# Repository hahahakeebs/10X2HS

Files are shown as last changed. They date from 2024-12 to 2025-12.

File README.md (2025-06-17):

# 10X2HS

A hotswap variant of [10x2](https://github.com/miketronic/10x2) by [miketronic](https://github.com/miketronic)

# these files are not verified yet, get them printed at your own risk

original readme preserved below




10x

[More pictures here](https://imgur.com/a/LNFxImS)

## Features

- 20 keys
- Low profile choc switches with CFX spacing (closer spacing then standard choc, only caps of size 16.50mm x 16.50mm will fit)
- RGB lighting (not on v3G)
- Waveshare RP2040 Zero controller
- QMK firmware
- [ZMK firmware - module here ](https://github.com/miketronic/zmk-keyboards-10x2/tree/main)

## Introduction

Capsule3 (which I've renamed to 10x2 thanks to the great suggestion by daveurr on Discord) is the third addition to my Capsule series, the first two not being worthy of being posted publicly haha.

The idea for this keyboard (and subsequent keymap) was to design a layout that avoids any lateral finger movement as you would on conventional full-sized keyboards. Moving your fingers only up and down on the columns provides a more enjoyable experience and can reduce or eliminate RSI (repetitve strain injury) in your fingers.

But how only 18 total letter keys? By building a custom firmware layout and using combos for less used letters, or where they "feel best". I performed some studies on letter frequency in the English language and most common bigrams and trigrams to determind the layout.

keyboard-layout

## Keycaps

As noted in the _Features_, I chose a narrower keyswitch spacing and thus they require narrower keycaps. CFX keycaps are commercially available from Chosfox, or you can print your own, for which I've included files. They easily print upside down on an FDM printer, and I use a textured baseplate.

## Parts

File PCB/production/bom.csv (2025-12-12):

Designator | Footprint | Quantity | Value | LCSC Part #
D1, D10, D11, D12, D13, D14, D15, D16, D17, D18, D19, D2, D20, D3, D4, D5, D6, D7, D8, D9 | D_SOD-123 | 20 | 1n4148
H01, H02, H03, H04, H05, H06, H07 | M2_Solder_nut_small_HS | 7 | M2 Solder Nut | C3020123
SW1, SW10, SW11, SW12, SW13, SW14, SW15, SW16, SW17, SW18, SW19, SW2, SW20, SW3, SW4, SW5, SW6, SW7, SW8, SW9 | choc hs v1v2 led | 20 | MX_SW_solder
SW21, SW22 | Panasonic_EVQPUL_EVQPUC | 2 | SW_Push

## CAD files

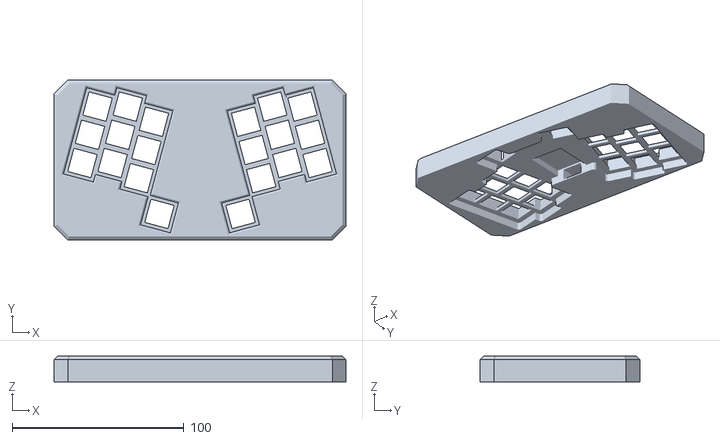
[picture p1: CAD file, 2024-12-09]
case/v3G/FULL_capsule3_v3G_plate.stl
170.0 x 93.1 x 15.0

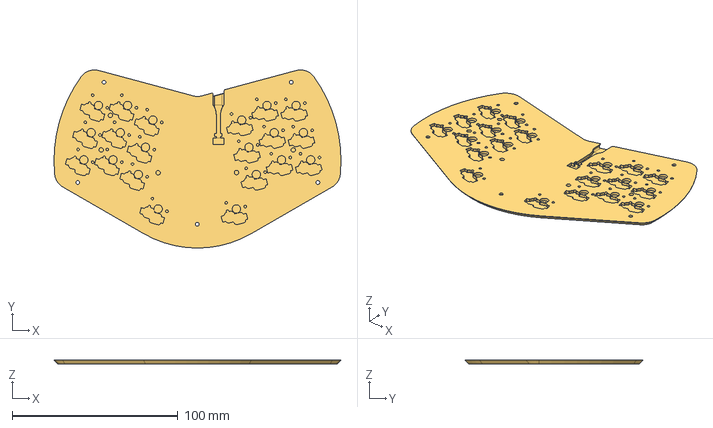
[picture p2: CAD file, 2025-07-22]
case/Aileron/10x2 Aileron v15 bottom with button.step
173.3 x 107.5 x 2.70 mm

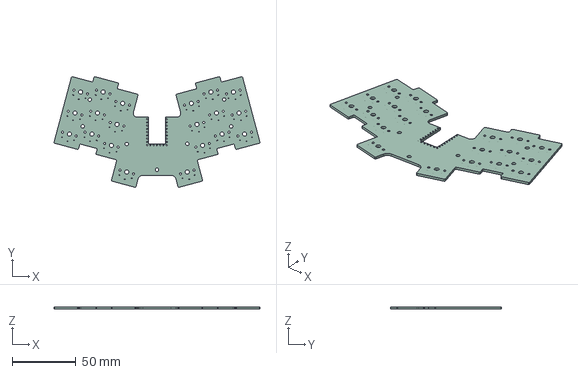
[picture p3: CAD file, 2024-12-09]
case/v3G/capsule3_v3G.step
161.0 x 86.5 x 1.60 mm

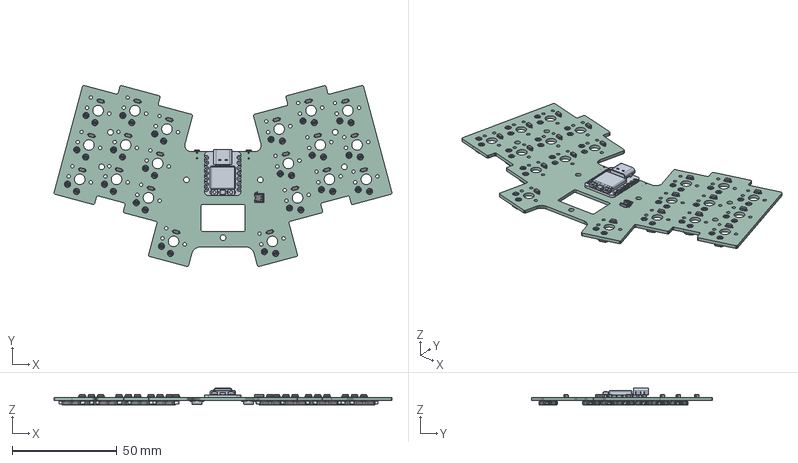
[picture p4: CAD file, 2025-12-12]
PCB/10X2HS.step
161.5 x 86.5 x 8.04 mm
CON_781710002
D_SOD-123 x 20
10X2HS 1.10.1
pin x 40
socket x 20
EVQPU-LC-02K x 2
10X2HS_PCB

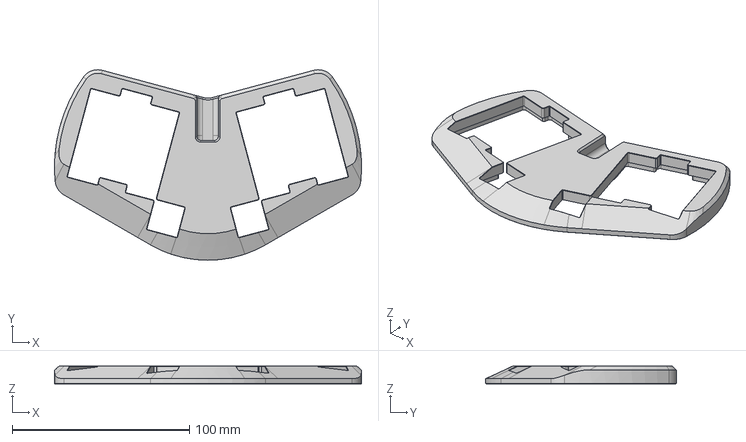
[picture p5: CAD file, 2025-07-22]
case/Aileron/10x2 Aileron v15 top no button.step
173.3 x 107.5 x 9.90 mm

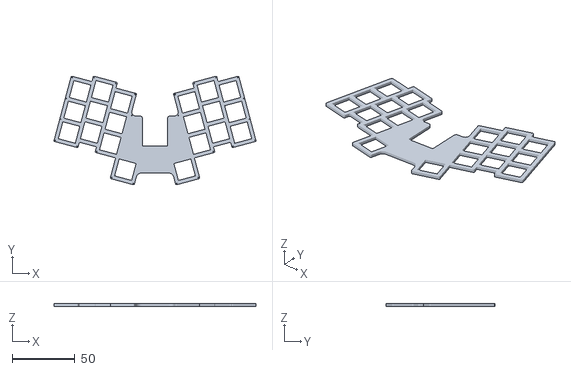
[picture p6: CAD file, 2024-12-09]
case/v3G/capsule3_v3G_plate v3.stl
161.0 x 86.5 x 2.00

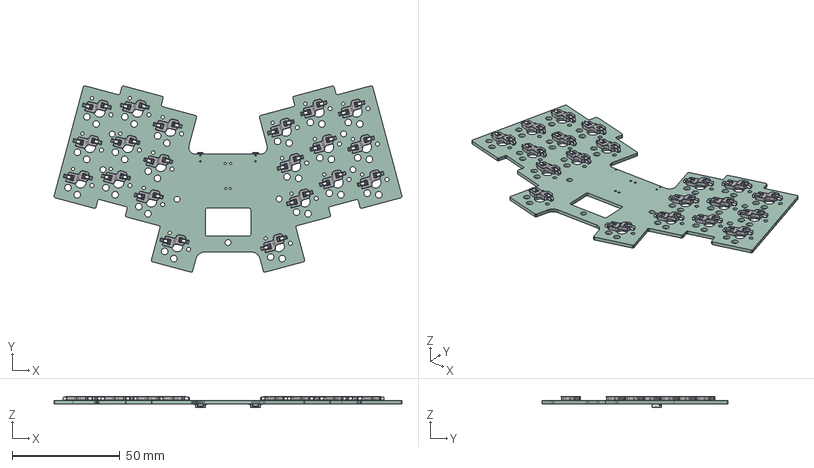
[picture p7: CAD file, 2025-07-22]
PCB/capsule3_wwa.step
161.5 x 86.5 x 5.12 mm
SW_Hotswap_Kailh_Choc_V1 x 20
EVQPU-LC-02K x 2
10X2HS_PCB

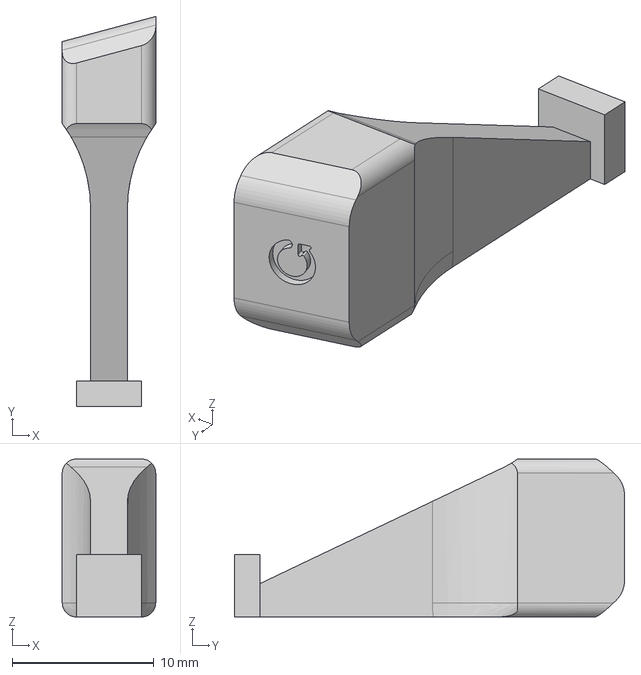
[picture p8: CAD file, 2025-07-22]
case/Aileron/10x2 Aileron v15 reset button.step
6.60 x 27.5 x 11.2 mm

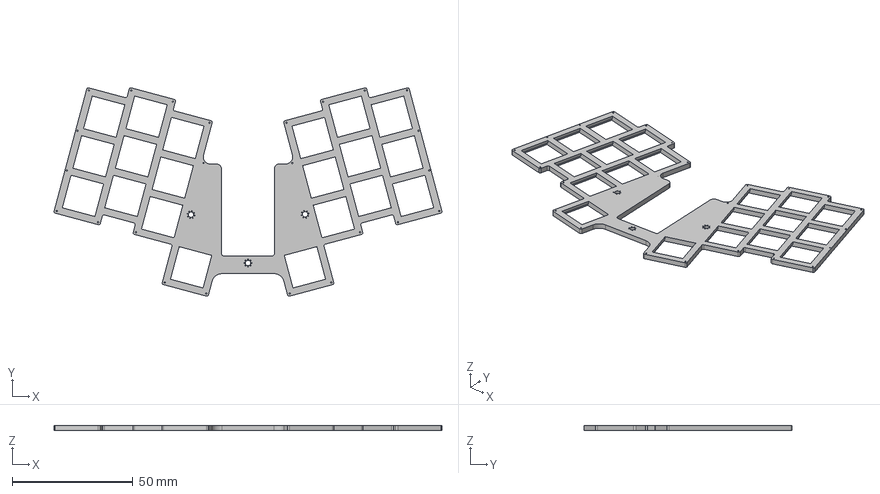
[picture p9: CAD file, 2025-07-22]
case/Aileron/10x2 Aileron v15 plate.step
161.0 x 86.5 x 2.20 mm

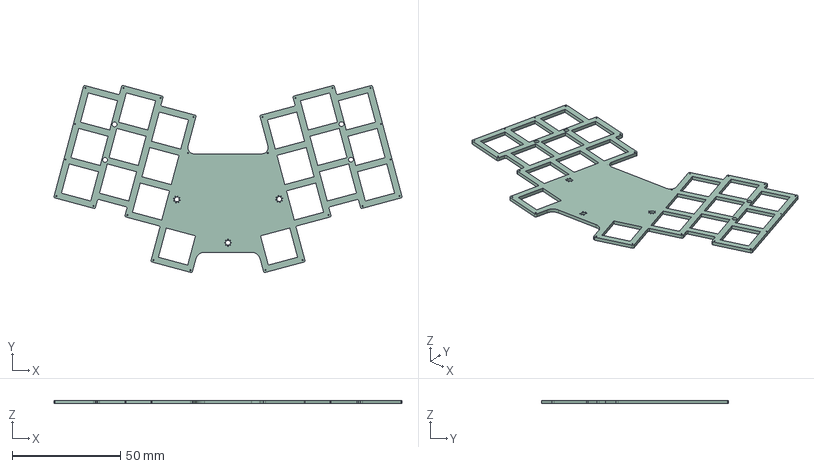
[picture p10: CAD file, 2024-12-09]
case/v3G/capsule3_v3G_plate.step
161.0 x 86.5 x 1.60 mm

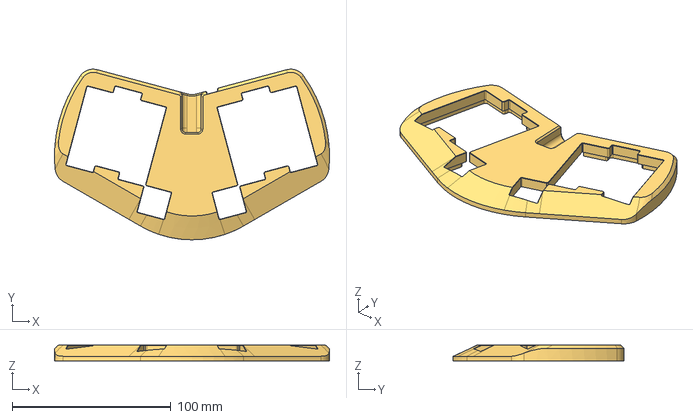
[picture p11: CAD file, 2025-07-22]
case/Aileron/10x2 Aileron v15 top with button.step
173.3 x 107.5 x 9.90 mm

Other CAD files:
case/Aileron/10x2 Aileron v15 bottom no button.step

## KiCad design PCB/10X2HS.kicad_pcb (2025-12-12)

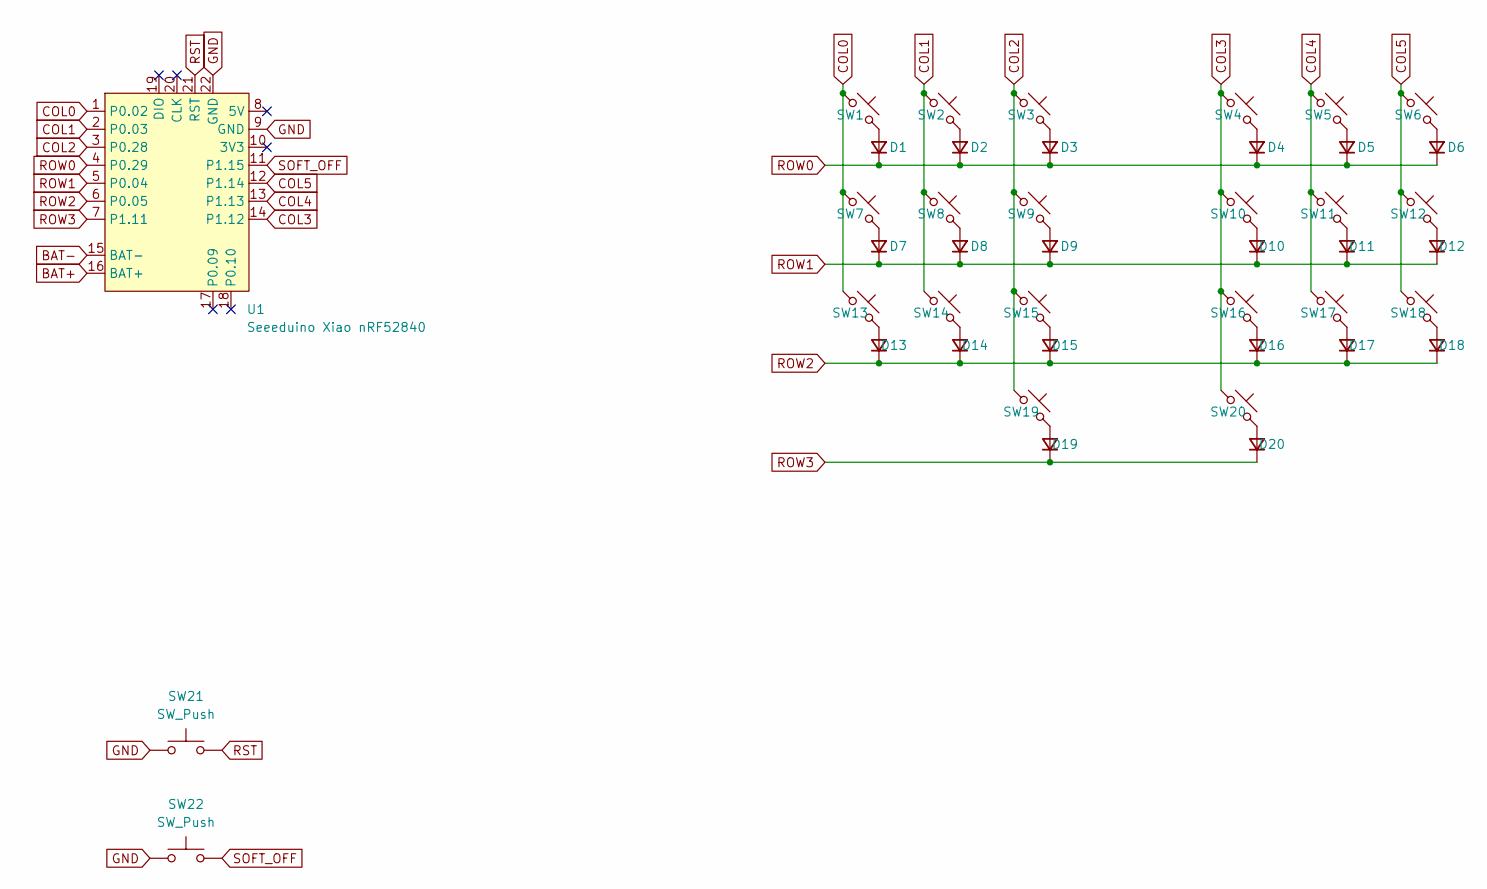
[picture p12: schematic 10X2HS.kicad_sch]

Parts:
D1, D2, D3, D4, D5, D6, D7, D8, D9, D10, D11, D12, D13, D14, D15, D16, D17, D18, D19, D20: 1n4148; D_SOD-123
SW1, SW2, SW3, SW4, SW5, SW6, SW7, SW8, SW9, SW10, SW11, SW12, SW13, SW14, SW15, SW16, SW17, SW18, SW19, SW20: MX_SW_solder; SW_MX_1u_rev
SW21, SW22: SW_Push; SW_PUSH_6mm
U1: Seeeduino Xiao nRF52840; Xiao_nRF52840_ACH

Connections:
BAT+: U1.16 (BAT+)
BAT-: U1.15 (BAT-)
COL0: SW1.1, SW7.1, SW13.1, U1.1 (P0.02)
COL1: SW2.1, SW8.1, SW14.1, U1.2 (P0.03)
COL2: SW3.1, SW9.1, SW15.1, SW19.1, U1.3 (P0.28)
COL3: SW4.1, SW10.1, SW16.1, SW20.1, U1.14 (P1.12)
COL4: SW5.1, SW11.1, SW17.1, U1.13 (P1.13)
COL5: SW6.1, SW12.1, SW18.1, U1.12 (P1.14)
GND: SW21.1, SW22.1, U1.9 (GND), U1.22 (GND)
unnamed: D1.2 (A), SW1.2
unnamed: D2.2 (A), SW2.2
unnamed: D3.2 (A), SW3.2
unnamed: D4.2 (A), SW4.2
unnamed: D5.2 (A), SW5.2
unnamed: D6.2 (A), SW6.2
unnamed: D7.2 (A), SW7.2
unnamed: D8.2 (A), SW8.2
unnamed: D9.2 (A), SW9.2
unnamed: D10.2 (A), SW10.2
unnamed: D11.2 (A), SW11.2
unnamed: D12.2 (A), SW12.2
unnamed: D13.2 (A), SW13.2
unnamed: D14.2 (A), SW14.2
unnamed: D15.2 (A), SW15.2
unnamed: D16.2 (A), SW16.2
unnamed: D17.2 (A), SW17.2
unnamed: D18.2 (A), SW18.2
unnamed: D19.2 (A), SW19.2
unnamed: D20.2 (A), SW20.2
ROW0: D1.1 (K), D2.1 (K), D3.1 (K), D4.1 (K), D5.1 (K), D6.1 (K), U1.4 (P0.29)
ROW1: D7.1 (K), D8.1 (K), D9.1 (K), D10.1 (K), D11.1 (K), D12.1 (K), U1.5 (P0.04)
ROW2: D13.1 (K), D14.1 (K), D15.1 (K), D16.1 (K), D17.1 (K), D18.1 (K), U1.6 (P0.05)
ROW3: D19.1 (K), D20.1 (K), U1.7 (P1.11)
RST: SW21.2, U1.21 (RST)
SOFT_OFF: SW22.2, U1.11 (P1.15)

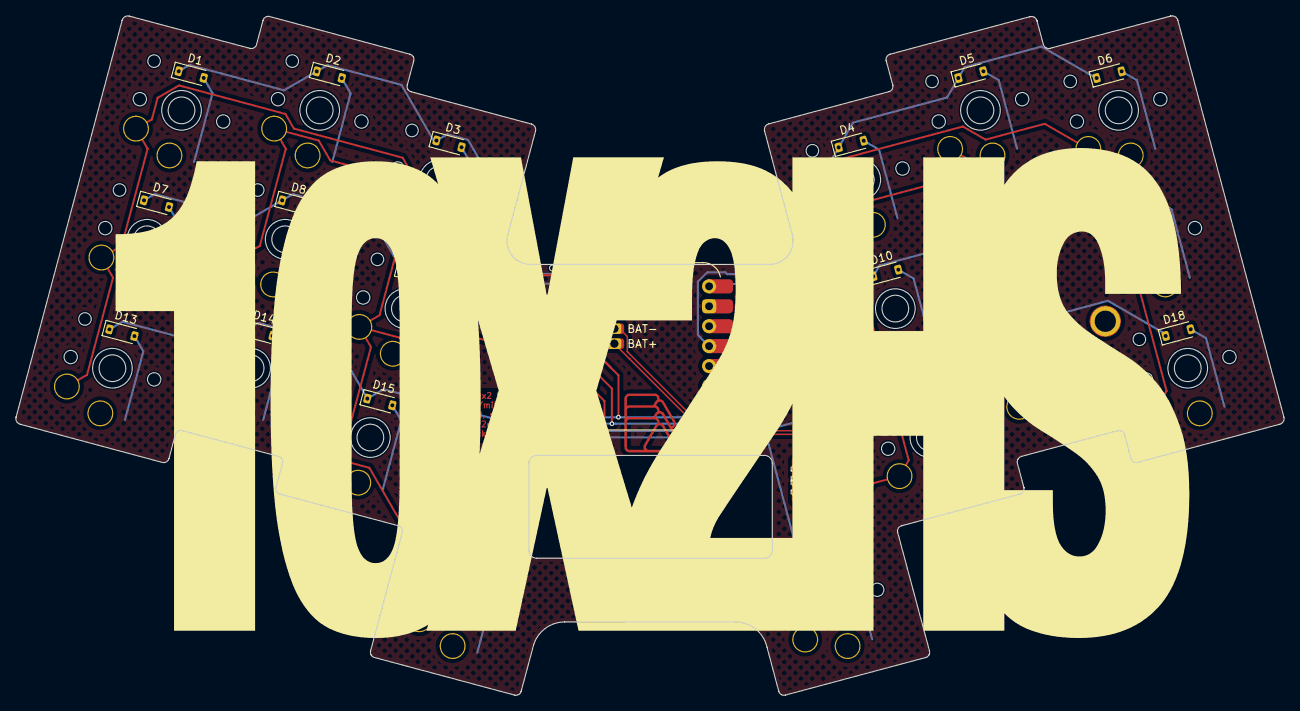
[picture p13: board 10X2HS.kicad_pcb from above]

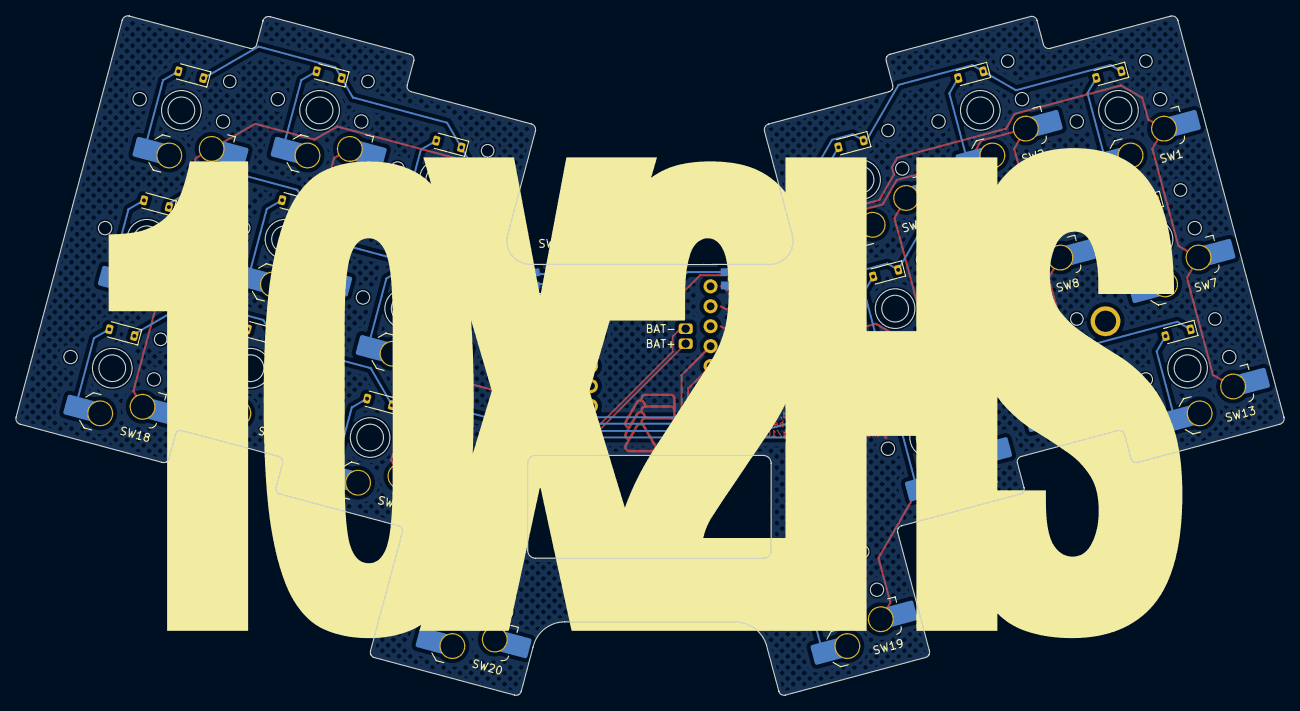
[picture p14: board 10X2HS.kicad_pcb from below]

Board: 2 copper layers, 161.5 x 86.5 mm, 50 parts (22 on the bottom side), 33 nets.

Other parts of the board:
H01, H02, H03, H04, H05, H06, H07: M2 Solder Nut; M2_Solder_nut_small_HS

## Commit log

2025-06-17 maybe complete, cleanup still needs done
    [10X2HS.kicad_sch, bom.csv, capsule3_v3G.kicad_pcb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]
2025-07-22 protos ordered, case designed, v.1 complete
    [10x2 Aileron v15 bottom no button.step, 10x2 Aileron v15 bottom with button.step, 10x2 Aileron v15 plate.step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]
2025-07-22 more updates I guess
    [10X2HS.kicad_sch, bom.csv, capsule3_v3G_bottom.kicad_pcb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]
2025-12-12 changed to nonplus xiao, add direct battery pads
    [10X2HS.kicad_pcb, 10X2HS.kicad_sch, 10X2HS.step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]

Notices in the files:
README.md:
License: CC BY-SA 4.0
